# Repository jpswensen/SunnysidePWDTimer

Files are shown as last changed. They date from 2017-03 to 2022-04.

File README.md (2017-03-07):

# SunnysidePWDTimer

This is an early prototype of a simple 4-lane pinewood derby timer created using the popular Internet of Things (IOT) device ESP8266, 
some cheap IR line detectors sensors, and a limit switch for the starting gate.

Parts List
================
* 1) Wemos D1 Mini - $7.49 (https://www.amazon.com/HiLetgo-NodeMcu-Development-ESP8266-Compatiable/dp/B01IXBWH9Y)
* 2) OSOYOO 10PCS IR Infrared Obstacle Avoidance Sensor Module for Arduino Smart Car Robot - $9.99 for a 10 pack (https://www.amazon.com/gp/product/B01I57HIJ0)
* 3) Limit switch for gate sensor (must have normally closed terminals) - $8.89 for a 20 pack (https://www.amazon.com/Gikfun-Micro-Switch-Arduino-EK1713/dp/B015W8S8NA)
* 4) Some 3D printed parts for mounting the sensor to the lanes and the limit switch

Details
================
The project contains both a cross-platform QT5 project for the PC side and Arduino code forht Wemos D1 Mini. They communicate through the
serial port built into the Wemos D1 Mini carrier board for the ESP8266 IOT mainboard. Here is a list of pin configurations:

 * D7 - Start gate limit switch
 * D1 - Lane A
 * D2 - Lane B
 * D5 - Lane C
 * D6 - Lane D

I plan on uploading the Solidworks and STL files for our particular track so that it would be easy for others to modify for their track.
This software is clearly not as fully functional as the Grand Prix Race Manager (TM) software, but it is free and the timer costs about $20-25
if you can get a bit of donated 3D printing from a parent or friend of the pack. I would welcome collaborators to make the software really fully
functional (e.g. support dens/groups/subgroups, printing certificates, etc.) I was actually really surprised when our pack was buying a new track
that was around $1,000 and even a cheap timer was over $219. The timer sold by the track manufacturer was really nice, but cost another $600
beyond the cost of the track.

Let me know if you have any questions and would like to collaborate.

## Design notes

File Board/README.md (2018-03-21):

# SunnysidePWDTimer

This is an initial schematic and board design for an 8-lane pinewood
derby timer.

THIS HAS NOT BEEN TESTED YET. THE CODE AND GUI INCLUDED IN THIS
PROJECT WERE BASED ON A 4-LANE HAND SOLDERED BOARD I MADE. THIS BOARD
IS BASED ON THAT AND SHOULD WORK FOR UP TO 8 LANES, BUT THE ARDUINO
CODE AND GUI CODE HAVE NOT BEEN UPDATED TO WORK WITH THIS DESIGN YET.

Parts List
================
* 1) Wemos D1 Mini - $7.49 (https://www.amazon.com/HiLetgo-NodeMcu-Development-ESP8266-Compatiable/dp/B01IXBWH9Y)
* 2) OSOYOO 10PCS IR Infrared Obstacle Avoidance Sensor Module for Arduino Smart Car Robot - $9.99 for a 10 pack (https://www.amazon.com/gp/product/B01I57HIJ0)
* 3) Limit switch for gate sensor (must have normally closed terminals) - $8.89 for a 20 pack (https://www.amazon.com/Gikfun-Micro-Switch-Arduino-EK1713/dp/B015W8S8NA)
* 4) Some 3D printed parts for mounting the sensor to the lanes and
the limit switch
* 5) See the file SunnysideTimersDigikey.csv for the rest of the
connector, pins, etc from Digikey

In total, I think this time would cost you about $80 to make an 8-lane
timer. If multiple people went together, and it was made in bulk, that
cost could probably be half that much (circuit boards are more
expensive in lower quantity and the cabling is expensive in short lengths). I also chose nice Molex Minifit Jr
connectors which end up being kindof pricy.

Details
================
Here is a description of the files

* SunnysideTimerV1.pro - The project file for Eagle PCB
* SunnysideTimerV1.sch - The schematic file for Eagle PCB
* SunnysideTimerV1.brd - The board file for Eagle PCB

The easiest way to get these made is to go to https://oshpark.com/ and
just upload the .brd file. They do all the processing and the price
comes out at around $30 for 3 boards. Not a bad price for a 14 day turnaround.

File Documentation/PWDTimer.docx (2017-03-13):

Pinewood Derby Timer Documentation

Last updated: 3/11/2017

By: John Swensen (jpswensen@gmail.com)

Overview

Non-technical overview

This is a very basic pinewood derby timer. Among its simple features, it can do the following:

- load/save race information from/to a comma-separated values (CSV) file
- run or re-run each heat of the race
- display and print the results.

It assumed that the track has four lanes and is based on the principle of every car running on every lane and the winner is that average of the times. It is generally understood that even really good tracks have some lanes that are better than others.

The main interface consists of 4 primary regions as seen in the following screen capture. The upper-left region (highlighted in red) contains a complete list of all the heats for the current set of race participants. The lower-left region (highlighted in purple) contains the details of the current heat. The upper-right region (highlighted in orange) contains buttons for configuring the race participants, opening a window with the complete race results, and for configuring the serial port communications with the timer hardware. The lower-right region (highlighted in green) contains buttons for controlling the current heat and some informational text about the current state of the timer hardware and the serial port. Each of these components will be explained later.

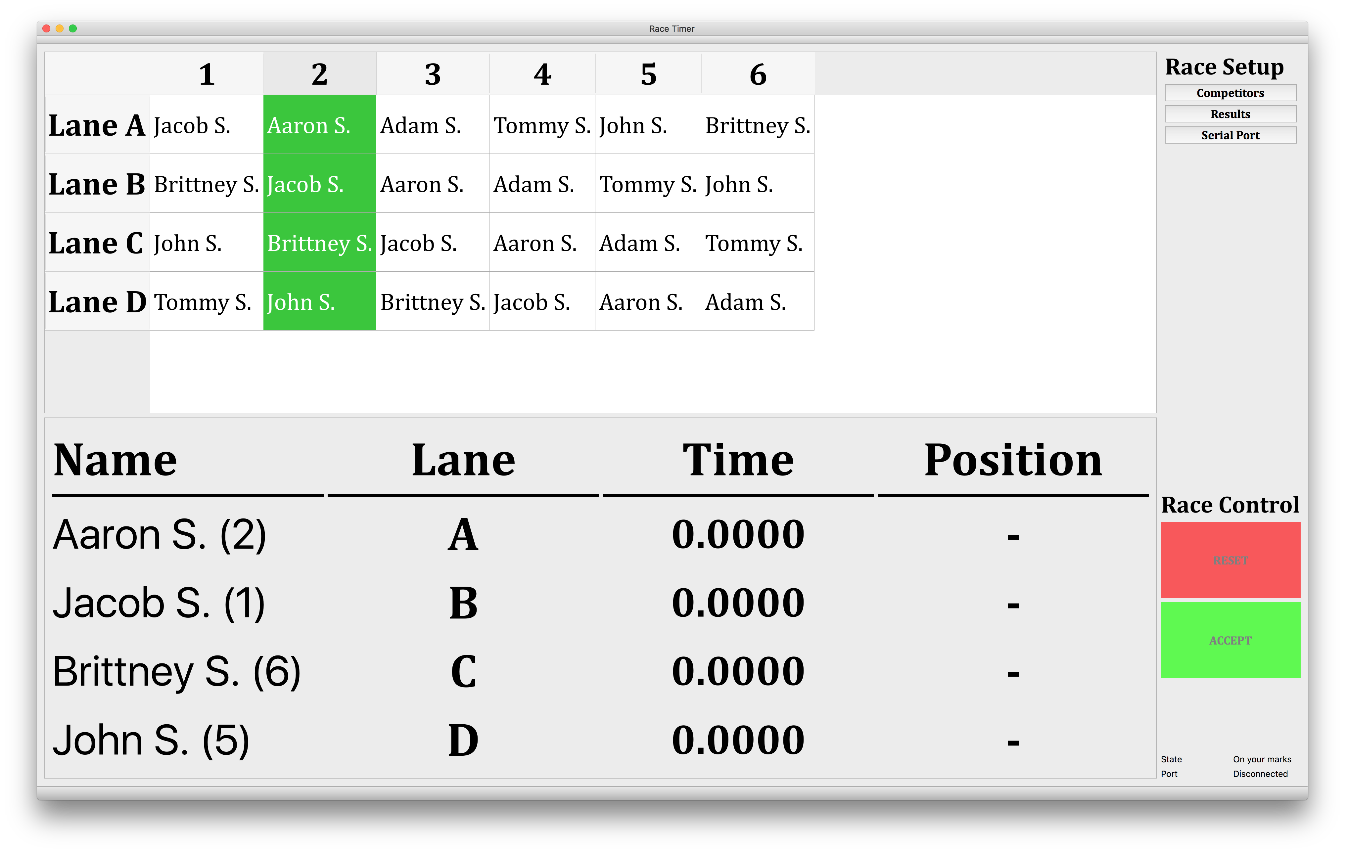
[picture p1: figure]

Technical overview

For the technically inclined, it is an Arduino-compatible ESP8266 microcontroller board (https://www.wemos.cc/product/d1-mini-pro.html ) with one pin interrupt for the start gate switch and four pin interrupts for the IR finish line sensors (https://www.amazon.com/gp/product/B01I57HIJ0). The PC timer software is written using the QT toolkit for cross-platform compatibility. It uses only standard QT toolkit libraries, so it should easily compile for MacOS, Windows, and Linux. The repository for the code can be found at https://github.com/jpswensen/SunnysidePWDTimer.

Quick Start

Import/Save from CSV file

While you can type in the contestants from a Competitors window within the app, many packs have a car check-in the day before. So, the software provides the alternative approach of entering the data into a spreadsheet as saving in CSV form. The import functionality of the timer software requires the follow fields per row: participant name, car name, lane A time, lane B time, lane C time, lane D time.

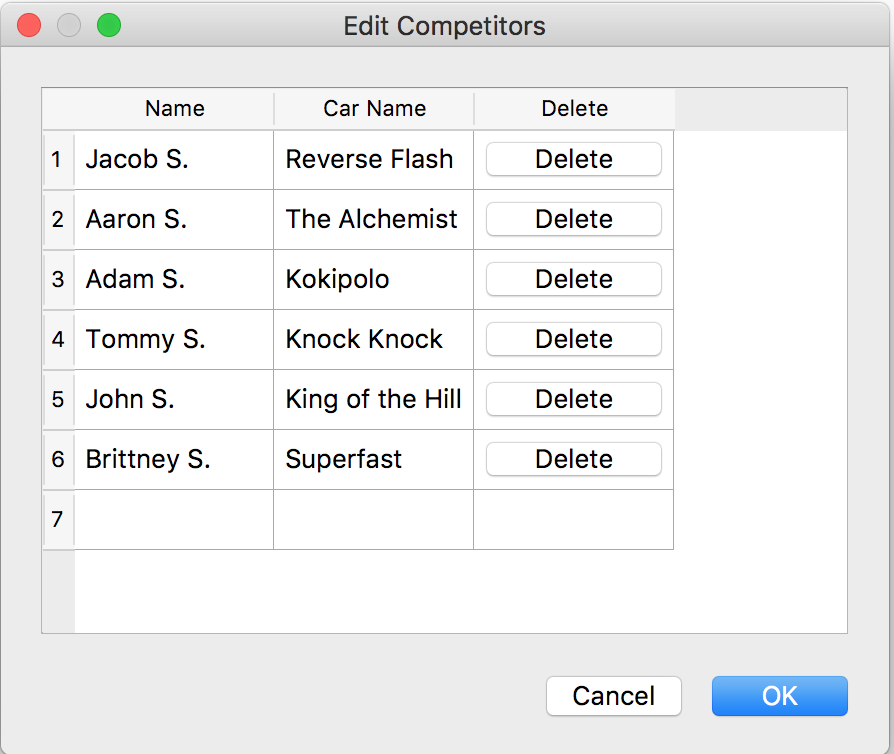
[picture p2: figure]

As the software has still had limited testing, I would recommend saving the race results after every heat is run. In that manner, if there is a crash of the software, then the times from the races that have been completed will not be lost.

Competitors Window

By clicking the Competitors button in the upper-right of the main window, it will open the dialog box shown below that allows the race manager to add and delete participants

WARNING: If the competitors button is used after the race has begun to add/remove a participant, it will clear out all the race time for heats that have already been completed. This is because the addition or removal of a racer will re-arrange how the heats are organized.

Heats Panel of the Main Window

The heats panel is populated by the list of participants, whether from the Competitors window or loaded from a CSV file. With N participants, there will be N heats.

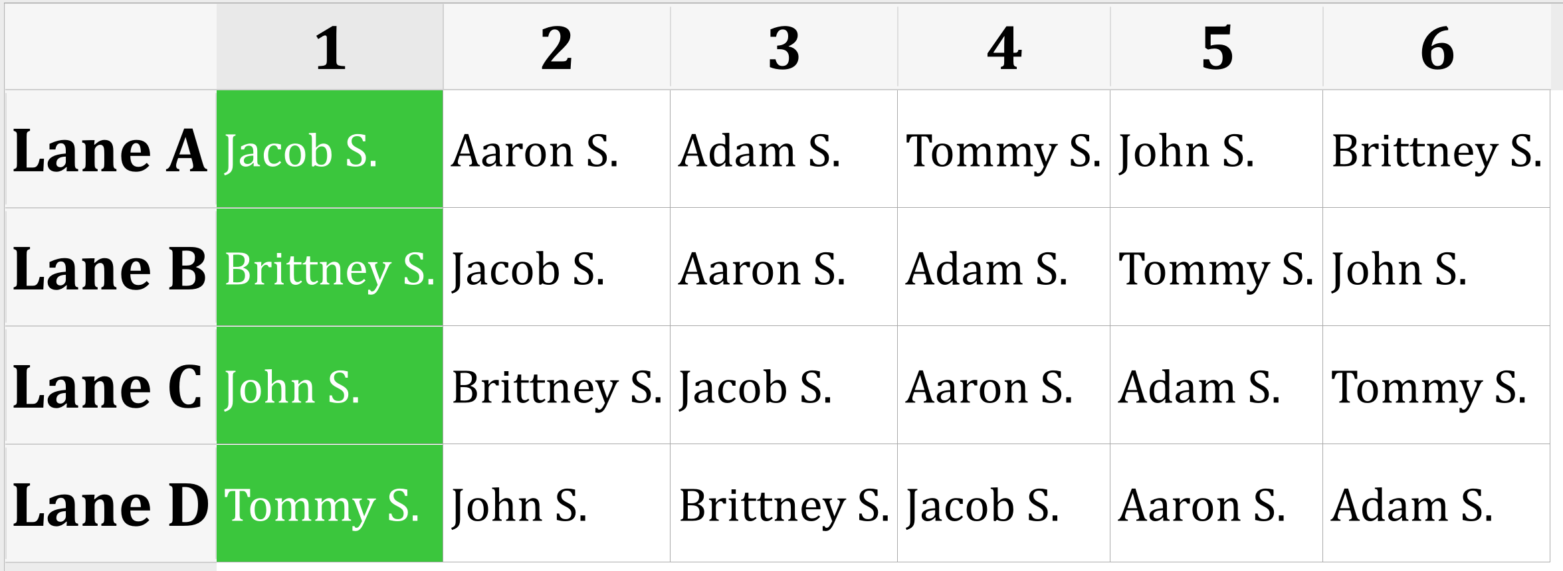
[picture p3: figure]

When the race times for a race heat have been accepted, a red square will appear next to the participant names in any heat that is complete. The race administrator must click on a column to change to a different heat. The current heat is highlighted in green, as shown in the previous figure.

Current Heat Panel of the Main Window

The current heat panel is populated based on which column is selected in the Heats Panel (as described above). This panel not only shows the car number, but also the lane indicator. We recommend having each car place a number on the back of the car during registration that matches the row in the CSV file. Additional put the (A,B,C,D) label on the back of each lane of the track. This will ensure that at the start of each heat it is easy to ensure each car is in the right lane. When the start gate is opened, each participant’s time begins to increase equally until each car crossed the finish line and the time for that lane stops. The participant’s finish position is also displayed. A screenshot of this lower-left panel is shown below. If the heat was successful, the race administrator pressed the “Accept” button to add the times for the current heat and marks the heat as completed in the Heats Panel.

Results Window

The Results window allows the race administrator to show the final results. This window allows the administrator to sort times by clicking on the header for the row. Some racers may be interested to know if they were the fastest on any individual lane, even if they weren’t the overall winners.

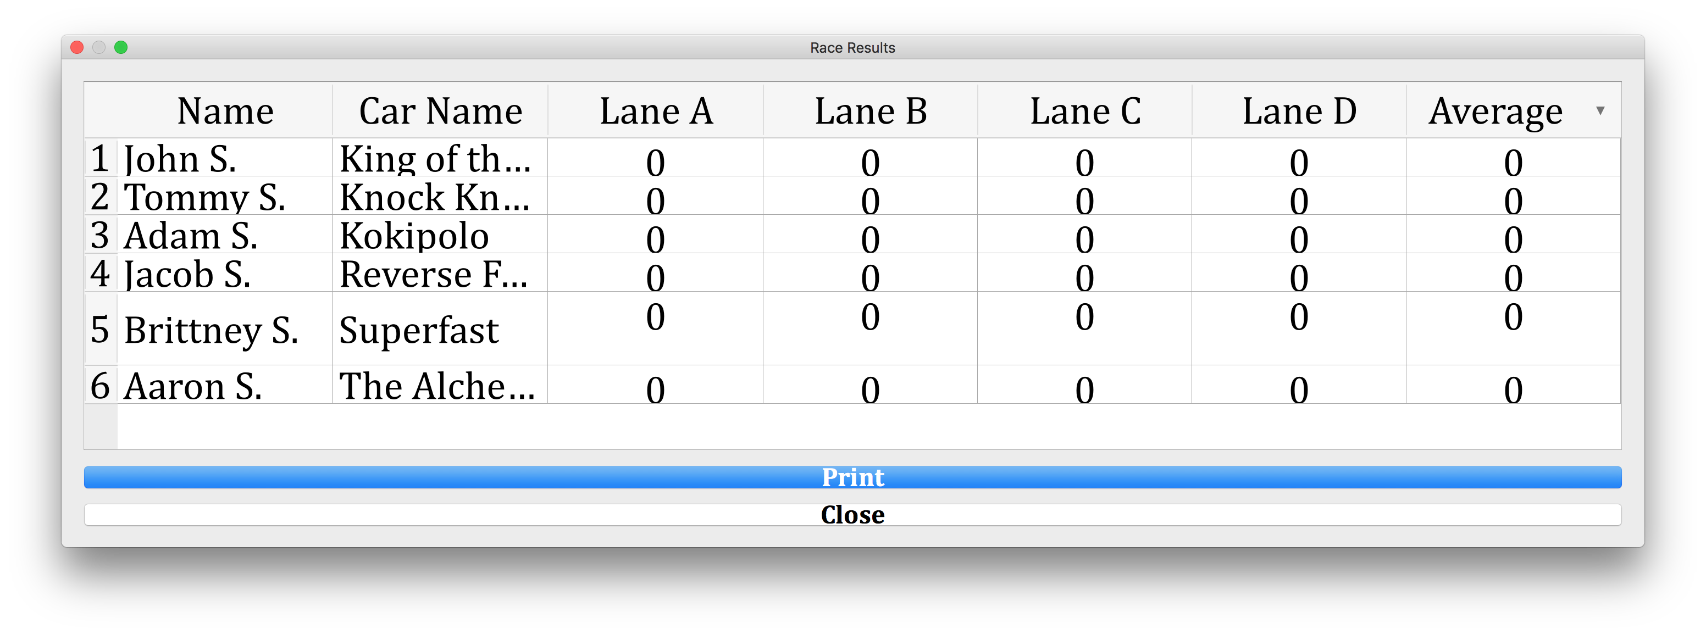
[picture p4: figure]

Serial Port Window

The Serial Port window allows the user to select the serial port used to communicate with the timer. Even though the timer is plugged into your computer using a USB cable, it shows up as a serial port. The easiest way to determine which serial port gets created when the USB cable is plugged in is to first open the Serial Port window before you plug in the timer. Then after you plug in the timer, open the Serial Port window again and see which serial port in the list is new.

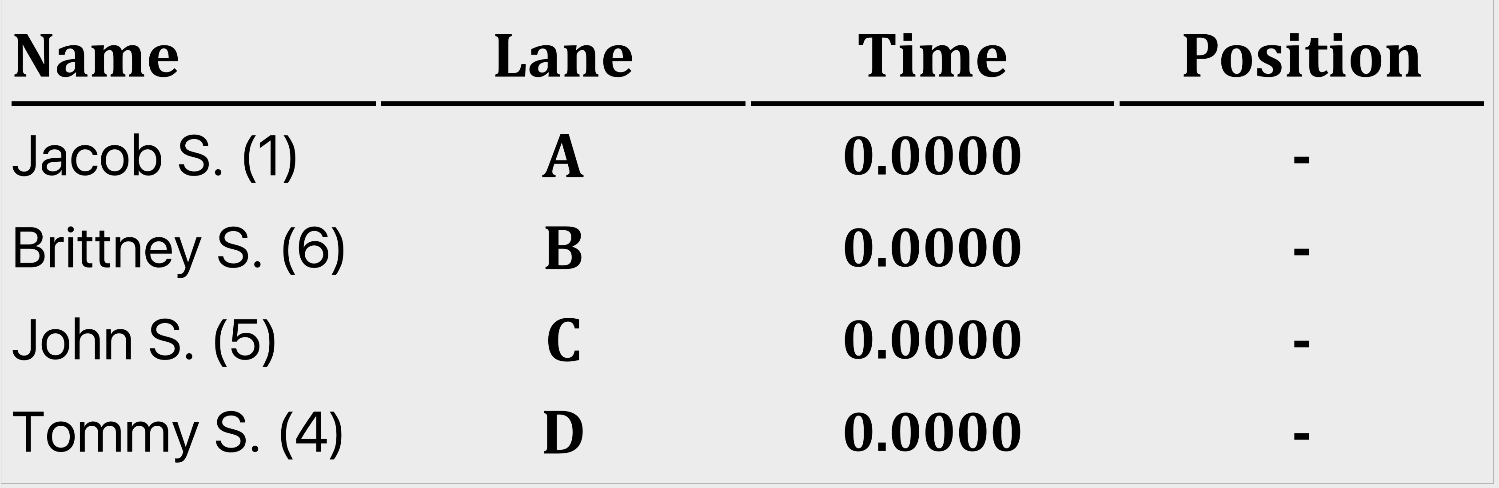
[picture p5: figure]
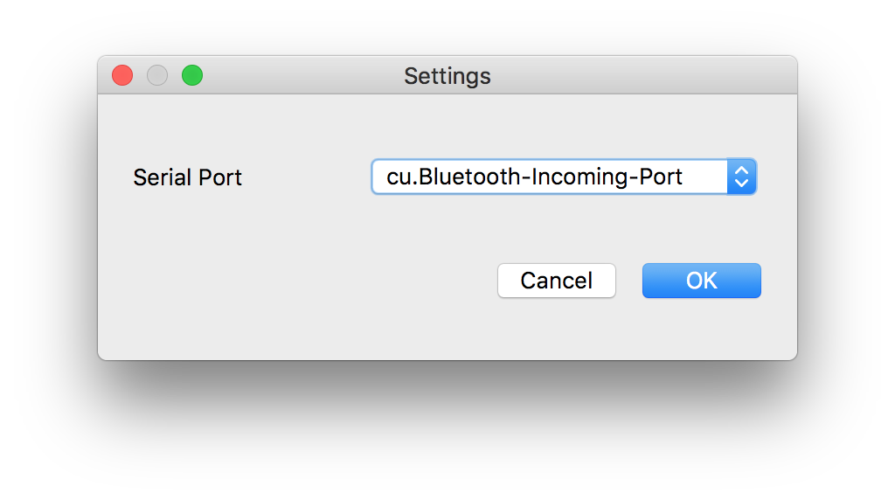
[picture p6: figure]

Race Control Panel

The Race Control panel is used to control the current heat. Due to current communications issues between the timer software and the timer hardware, after the heat has been changed, press the Reset button multiple times until the Time column of the Heat Panel is all zeros (0.0000) and the Position column is empty (‘-‘).

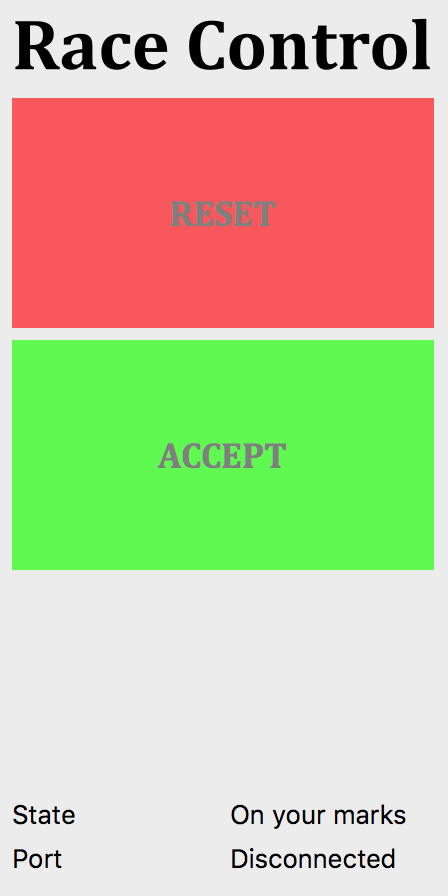
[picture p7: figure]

After the Reset button has been pressed, the State text will change to “On your marks (close gate)”. Once the start gate has been closed, the State text will change to “Get set”. The timer is now just waiting for the gate to be opened.

The Accept button will store the results of the current heat and update the Heats Panel.

Hardware Connections

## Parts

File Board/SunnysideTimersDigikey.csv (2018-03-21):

Index | Quantity | Part Number | Description | Customer Reference | Available Quantity | Backorder Quantity | Unit Price USD | Extended Price USD
1 | 10 | WM3801-ND | CONN HEADER 4POS 4.2MM VERT TIN |  | 10 | 0 | 0.68 | 6.8
2 | 2 | WM3800-ND | CONN HEADER 2POS 4.2MM VERT TIN |  | 2 | 0 | 0.62 | 1.24
3 | 8 | WM3701-ND | CONN RECEPT 4POS DUAL |  | 8 | 0 | 0.31 | 2.48
4 | 2 | WM3700-ND | CONN RECEPT 2POS DUAL |  | 2 | 0 | 0.28 | 0.56
5 | 50 | WM2503-ND | CONN TERM FEMALE 22-28AWG TIN |  | 50 | 0 | 0.1148 | 5.74
6 | 2 | EJ503A-ND | CONN PWR JACK 2.1X5.5MM SOLDER |  | 2 | 0 | 2.02 | 4.04
7 | 2 | 993-1236-ND | AC/DC WALL MOUNT ADAPTER 5V 3W |  | 2 | 0 | 5.26 | 10.52
8 | 1 | CE2104N-25-ND | CABLE 4COND 22AWG NAT SHLD 25' |  | 0 | 1 | 9.15 | 9.15
9 | 1 | C1362-21-50-ND | CABLE SPEAKER 2COND 22AWG 50' |  | 1 | 0 | 10.21 | 21
NONDIGIKEY
Amazon (cheaper from aliexpress) | 2 | WEMOS D1 Mini |  |  | 1 | 0 | $8.99 | 8.99
OshPark | 3 |  |  |  | 3 |  | $10 | 31.1
 |  |  |  |  |  |  |  | 101.62 | TOTAL

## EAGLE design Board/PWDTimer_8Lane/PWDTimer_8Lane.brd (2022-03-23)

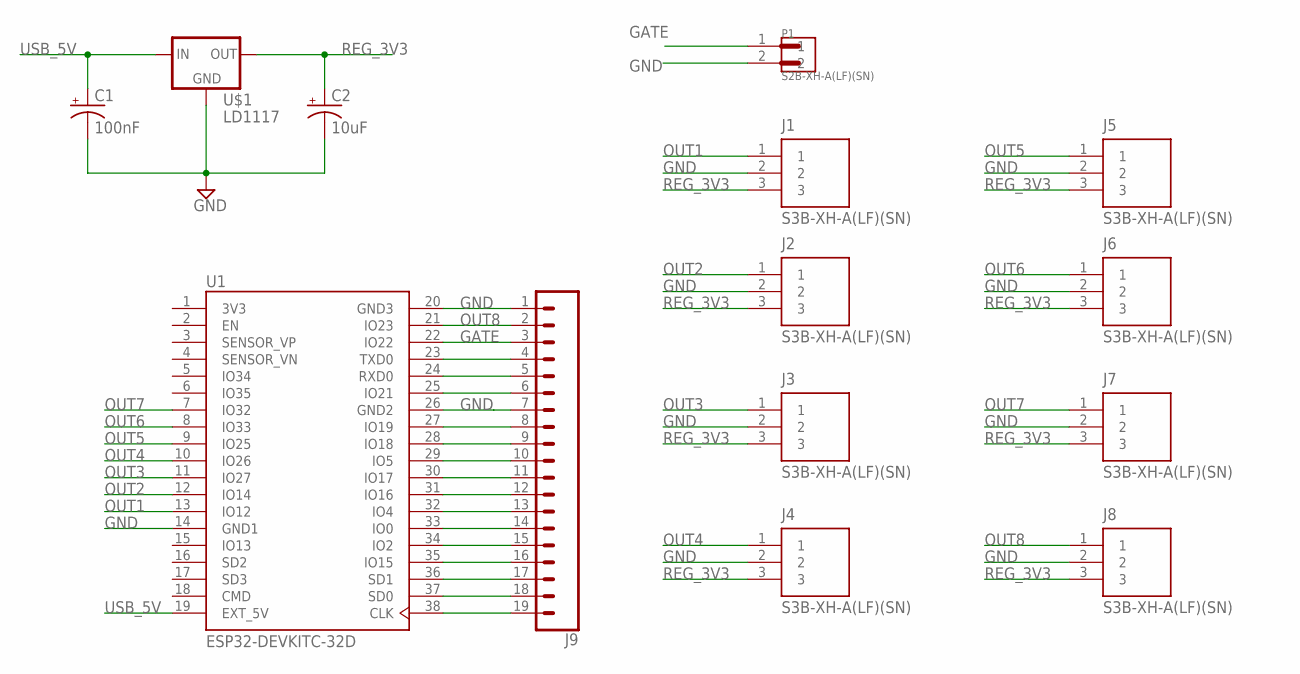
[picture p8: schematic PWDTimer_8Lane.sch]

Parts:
C1: 100nF; CPOL-RADIAL-2.5MM-5MM
C2: 10uF; CPOL-RADIAL-2.5MM-5MM
J1, J2, J3, J4, J5, J6, J7, J8: S3B-XH-A(LF)(SN); JST_S3B-XH-A(LF)(SN)
J9: CONN_191X19_NO_SILK; 1X19_NO_SILK
P1: S2B-XH-A(LF)(SN); JST_S2B-XH-A(LF)(SN)
U1: ESP32-DEVKITC-32D; MODULE_ESP32-DEVKITC-32D
U$1: LD1117; TO220

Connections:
3V3: U1.1 (3V3)
GATE: J9.3, P1.1, U1.22 (IO22)
GND: C1.2 (-), C2.2 (-), J1.2, J2.2, J3.2, J4.2, J5.2, J6.2, J7.2, J8.2, J9.1, J9.7, P1.2, U1.14 (GND1), U1.20 (GND3), U1.26 (GND2), U$1.1 (GND)
unnamed: J9.4, U1.23 (TXD0)
unnamed: J9.5, U1.24 (RXD0)
unnamed: J9.6, U1.25 (IO21)
unnamed: J9.8, U1.27 (IO19)
unnamed: J9.9, U1.28 (IO18)
unnamed: J9.10, U1.29 (IO5)
unnamed: J9.11, U1.30 (IO17)
unnamed: J9.12, U1.31 (IO16)
unnamed: J9.13, U1.32 (IO4)
unnamed: J9.14, U1.33 (IO0)
unnamed: J9.15, U1.34 (IO2)
unnamed: J9.16, U1.35 (IO15)
unnamed: J9.17, U1.36 (SD1)
unnamed: J9.18, U1.37 (SD0)
unnamed: J9.19, U1.38 (CLK)
OUT1: J1.1, U1.13 (IO12)
OUT2: J2.1, U1.12 (IO14)
OUT3: J3.1, U1.11 (IO27)
OUT4: J4.1, U1.10 (IO26)
OUT5: J5.1, U1.9 (IO25)
OUT6: J6.1, U1.8 (IO33)
OUT7: J7.1, U1.7 (IO32)
OUT8: J8.1, J9.2, U1.21 (IO23)
REG_3V3: C2.1 (+), J1.3, J2.3, J3.3, J4.3, J5.3, J6.3, J7.3, J8.3, U$1.2 (OUT)
USB_5V: C1.1 (+), U1.19 (EXT_5V), U$1.3 (IN)

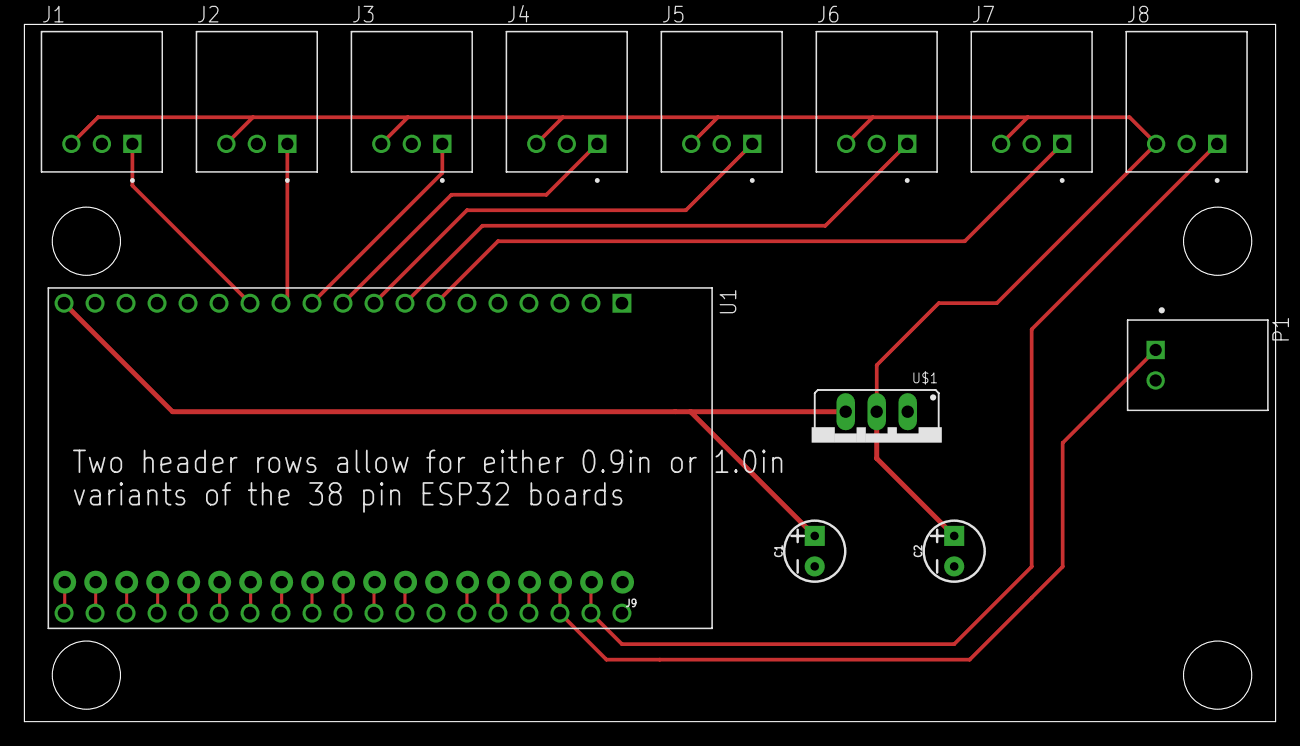
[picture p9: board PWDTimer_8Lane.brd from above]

Board: 2 copper layers, 102.5 x 57.1 mm, 14 parts (0 on the bottom side), 27 nets.

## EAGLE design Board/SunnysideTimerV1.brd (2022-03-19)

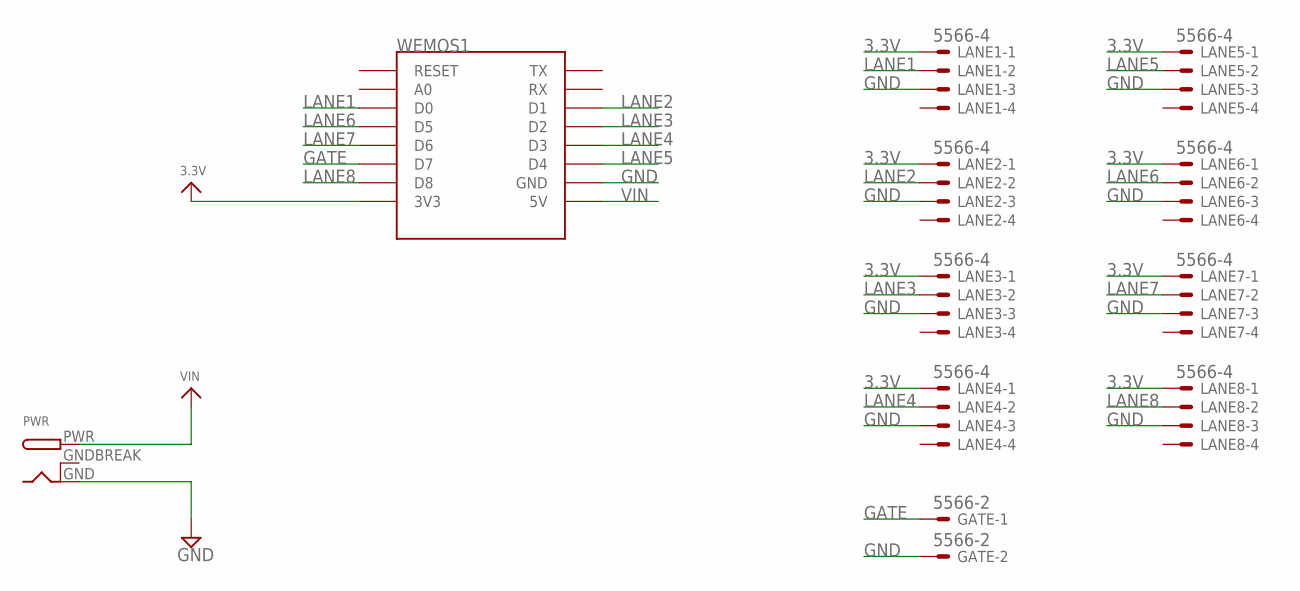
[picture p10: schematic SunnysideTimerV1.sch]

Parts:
GATE: 5566-2
LANE1, LANE2, LANE3, LANE4, LANE5, LANE6, LANE7, LANE8: 5566-4
PWR: DCBARRELPTH; DCJACK_2MM_PTH
WEMOS1: WEMOS-D1-MINI

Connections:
3.3V: LANE1.1, LANE2.1, LANE3.1, LANE4.1, LANE5.1, LANE6.1, LANE7.1, LANE8.1, WEMOS1.3V3
GATE: GATE.1, WEMOS1.D7
GND: GATE.2, LANE1.3, LANE2.3, LANE3.3, LANE4.3, LANE5.3, LANE6.3, LANE7.3, LANE8.3, PWR.GND, WEMOS1.GND
GNDBREAK: PWR.GNDBREAK
LANE1: LANE1.2, WEMOS1.D0
LANE2: LANE2.2, WEMOS1.D1
LANE3: LANE3.2, WEMOS1.D2
LANE4: LANE4.2, WEMOS1.D3
LANE5: LANE5.2, WEMOS1.D4
LANE6: LANE6.2, WEMOS1.D5
LANE7: LANE7.2, WEMOS1.D6
LANE8: LANE8.2, WEMOS1.D8
VIN: PWR.PWR, WEMOS1.5V

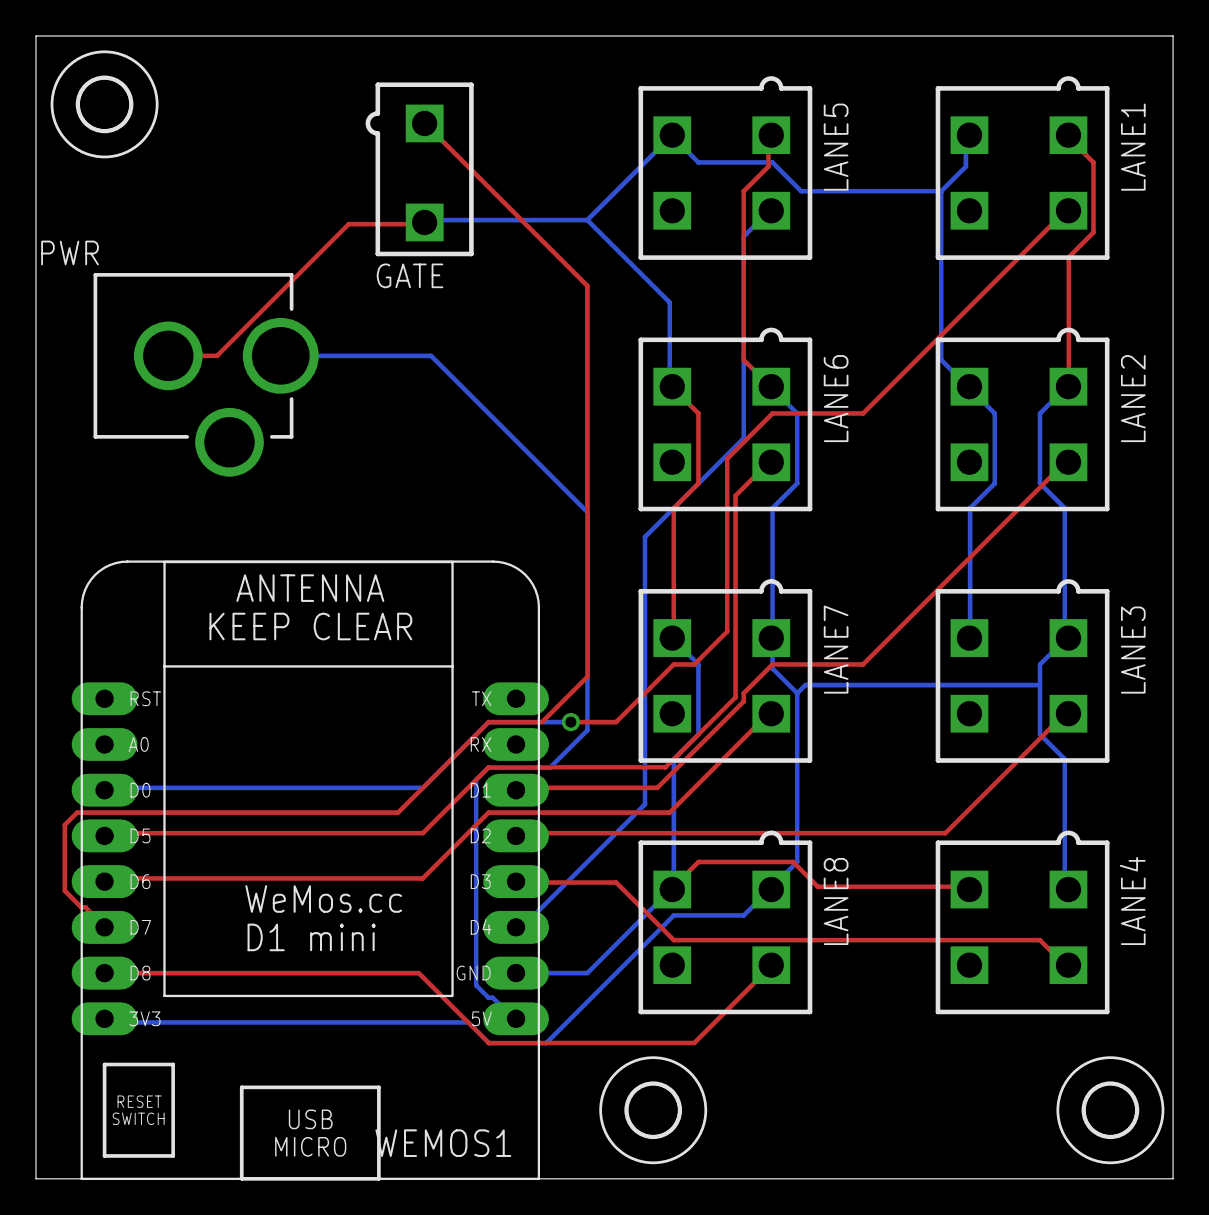
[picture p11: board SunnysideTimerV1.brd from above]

Board: 2 copper layers, 63.2 x 63.5 mm, 14 parts (0 on the bottom side), 12 nets.

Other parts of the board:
U$3, U$4, U$5: 2,8

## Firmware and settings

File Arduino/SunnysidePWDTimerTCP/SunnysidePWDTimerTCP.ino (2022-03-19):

/*
   Copyright (c) 2017, John Swensen
   All rights reserved.

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
   THIS SOFTWARE IS PROVIDED BY THE COPYRIGHT HOLDERS AND CONTRIBUTORS "AS IS" AND
   ANY EXPRESS OR IMPLIED WARRANTIES, INCLUDING, BUT NOT LIMITED TO, THE IMPLIED
   WARRANTIES OF MERCHANTABILITY AND FITNESS FOR A PARTICULAR PURPOSE ARE
   DISCLAIMED. IN NO EVENT SHALL THE COPYRIGHT HOLDER OR CONTRIBUTORS BE LIABLE FOR
   ANY DIRECT, INDIRECT, INCIDENTAL, SPECIAL, EXEMPLARY, OR CONSEQUENTIAL DAMAGES
   (INCLUDING, BUT NOT LIMITED TO, PROCUREMENT OF SUBSTITUTE GOODS OR SERVICES;
   LOSS OF USE, DATA, OR PROFITS; OR BUSINESS INTERRUPTION) HOWEVER CAUSED AND ON
   ANY THEORY OF LIABILITY, WHETHER IN CONTRACT, STRICT LIABILITY, OR TORT
   (INCLUDING NEGLIGENCE OR OTHERWISE) ARISING IN ANY WAY OUT OF THE USE OF THIS
   SOFTWARE, EVEN IF ADVISED OF THE POSSIBILITY OF SUCH DAMAGE.
*/

/* 
  This version of the timer firmware creates a WiFi access point and provides a TCP socket on it.
  This can still be run using the standard serial interface or can be connected to as an access point.
  NOTE: The reason for extending this to a WIFI solution was so that the computer/projector do not
        have to be near the finish line of the race. You will still need to run power to the finish line,
        but you won't need a long USB cable and monitor cable to have a better computer/projector location.
*/

#define USE_US_TIMER 1

#include <ESP8266WiFi.h>
#include <WiFiClient.h>

#include <algorithm>

#define LANE1_PIN D0
#define LANE2_PIN D1
#define LANE3_PIN D2
#define LANE4_PIN D3
#define LANE5_PIN D4
#define LANE6_PIN D5
#define LANE7_PIN D6
#define LANE8_PIN D8

#define STARTGATE_PIN D7



// Enums for maintaining the race and messaging information 
typedef enum RecvMessageEnum {
  UNDEFINED_MSG = 0,
  RESET_MSG
} RecvMessage_t;


typedef enum TimerStateEnum {
  UNDEFINED = 0,
  RESET,
  SET,
  IN_RACE,
  FINISHED
} TimerState_t;


// Variables for determining the state of the race and car times
#define NUM_TIMERS 8
TimerState_t state = RESET;
long startTime = 0;
long endTime[NUM_TIMERS] = {0, 0, 0, 0, 0, 0, 0, 0};


// Variables for configuring the communications
#define SERIAL_BAUD 115200

#define MAX_SRV_CLIENTS 1
#define TCP_PORT        8080

const char *ssid = "PWDTIMER";
const char *password = "PWDTIMER";
WiFiServer server(TCP_PORT);
WiFiClient serverClients[MAX_SRV_CLIENTS];


/**************************************************************************************************************
 * INTERRUPT HANDLING
 **************************************************************************************************************/

// Declare and ISR handler that can deal with any of the lanes
void laneInterrupt(int num)
{
  if (endTime[num] == 0)
  {
    //Serial.println("Lane1 interrupt");
    endTime[num] = micros();

    bool is_finished = true;
    for (int i = 0 ; i < NUM_TIMERS ; i++)
    {
      is_finished &= (endTime[i] != 0);
    }
    state = is_finished ? FINISHED : IN_RACE;    
  }
}

// Create a templated function that uses the ISR number as the template parameter
template<int N>
void laneInterruptISR() {
  laneInterrupt(N);
}

void startGateInterrupt() {
  //Serial.println("Start gate interrupt");
  if (state == SET)
  {
    startTime = micros();
    
    endTime[0] = 0;
    endTime[1] = 0;
    endTime[2] = 0;
    endTime[3] = 0;
    endTime[4] = 0;
    endTime[5] = 0;
    endTime[6] = 0;
    endTime[7] = 0;

    state = IN_RACE;
  }
}
 
void setupInterrupts () {
  // Set up the gate and lane pins as inputs with weak pull-ups
  pinMode(LANE1_PIN, INPUT_PULLUP);
  pinMode(LANE2_PIN, INPUT_PULLUP);
  pinMode(LANE3_PIN, INPUT_PULLUP);
  pinMode(LANE4_PIN, INPUT_PULLUP);
  pinMode(LANE5_PIN, INPUT_PULLUP);
  pinMode(LANE6_PIN, INPUT_PULLUP);
  pinMode(LANE7_PIN, INPUT_PULLUP);
  pinMode(LANE8_PIN, INPUT_PULLUP);
  pinMode(STARTGATE_PIN, INPUT_PULLUP);

  // Attach the interrupts for each of the lanes.
  // NOTE: Here we are using some C++ template magic above to only have to declare the ISR once.
  attachInterrupt(LANE1_PIN, laneInterruptISR<1>, FALLING);
  attachInterrupt(LANE2_PIN, laneInterruptISR<2>, FALLING);
  attachInterrupt(LANE3_PIN, laneInterruptISR<3>, FALLING);
  attachInterrupt(LANE4_PIN, laneInterruptISR<4>, FALLING);
  attachInterrupt(LANE5_PIN, laneInterruptISR<5>, FALLING);
  attachInterrupt(LANE6_PIN, laneInterruptISR<6>, FALLING);
  attachInterrupt(LANE7_PIN, laneInterruptISR<7>, FALLING);
  attachInterrupt(LANE8_PIN, laneInterruptISR<8>, FALLING);

  // Attach the starting gate interrupt
  attachInterrupt(STARTGATE_PIN, startGateInterrupt, FALLING);
}


/**************************************************************************************************************
 * COMMUNICATIONS : TCP (DATA) AND SERIAL (DEBUG)
 **************************************************************************************************************/
void setupCommunications() {
  delay(1000);
  Serial.begin(SERIAL_BAUD);
  Serial.println();

  Serial.print("Setting up soft-AP...");
  boolean result = WiFi.softAP(ssid, password);
  if(result == true)
  {
    IPAddress myIP = WiFi.softAPIP();
    Serial.print("Success!");
    Serial.print("    soft-AP IP address: ");
    Serial.println(myIP);
  }
  else
  {
    Serial.println("Failed to set up soft-AP");
  }

}
    

void setupTCPserver() {  
  server.begin();
  server.setNoDelay(true); 
}

void processTCPserverConnections() {
  uint8_t i;
  if (server.hasClient()){
    for(i = 0; i < MAX_SRV_CLIENTS; i++){
      if (!serverClients[i] || !serverClients[i].connected()){
        if(serverClients[i]) serverClients[i].stop();
        serverClients[i] = server.available();
        continue;
      }
    }
    //no free spot
    WiFiClient serverClient = server.available();
    serverClient.stop();
  }
}

RecvMessage_t readMessage()
{
  // TODO: Check both the serial and the TCP for a message
  
  // Check whether a reset command has been sent via serial
  if (Serial.available() >=5)
  {
    String readString;
    while (Serial.available()) {
      char c = Serial.read();  //gets one byte from serial buffer
      readString += c; //makes the string readString
    }

    
    if (readString.equals("RESET"))
    {
      return RESET_MSG;
    }
  }
  
  return UNDEFINED_MSG;
}

void sendMessage(int currentTime)
{
  // Build the message to be sent
  char msgBuffer[512];
  sprintf(msgBuffer, "$%d,%d,%d,%d,%d,%d,%d,%d,%d,%d,%d*", state, startTime, currentTime,
                     endTime[0], endTime[1], endTime[2], endTime[3],
                     endTime[4], endTime[5], endTime[6], endTime[7]);

  // Send the message over serial
  Serial.println(msgBuffer);

  // Send the message over TCP (if connected)
  if (serverClients[0] && serverClients[0].connected()){
    serverClients[0].println(msgBuffer);
  }
}

/**************************************************************************************************************
 * VARIOUS OTHER FUNCTIONS
 **************************************************************************************************************/
void resetRace() {
  state = RESET;
  startTime = -1;
  for (int i = 0 ; i < NUM_TIMERS ; i++) {
    endTime[i] = 0; 
  }
}


/**************************************************************************************************************
 * SETUP AND LOOP
 **************************************************************************************************************/
void setup() {
  delay(1000);
  setupCommunications();

  setupTCPserver();

  setupInterrupts();
}

void loop() {

  // Process TCP connects and disconnects
  processTCPserverConnections();

  // Read in messages from either serial or TCP
  RecvMessage_t msg = readMessage();
  if (msg == RESET_MSG) {
    resetRace();
  }
  

  long currentTime = -1;
  
  switch (state) {
    case RESET:
      startTime = -1;

      if (digitalRead(STARTGATE_PIN) == HIGH)
      {
        state = SET;
      }
      else
      {
        sendMessage(currentTime);
      }
      
      break;

    case SET:
      sendMessage(currentTime);
      break;

    case IN_RACE:
      currentTime = micros();
      sendMessage(currentTime);
      break;

    case FINISHED:
      currentTime = std::max(std::max(std::max(endTime[0], endTime[1]),endTime[2]),endTime[3]);
      sendMessage(currentTime);
      break;
    
  }

  delay(50);
  
}

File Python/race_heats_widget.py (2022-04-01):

import sys
from PyQt5 import QtWidgets, uic, QtCore
from PyQt5.QtWidgets import *
from PyQt5.QtGui import *
from PyQt5.QtCore import *
import time
import configparser
from pathlib import Path
import os
import typing

from resources import *
from racefiles import *

class RaceHeatsWidget(QWidget):
    num_lanes = 0
    racedata = None
    
    heatSelectionCallback = None

    def __init__(self,parent=None):
        QWidget.__init__(self,parent)
        uic.loadUi(resource_path('race_heats_widget.ui'),self)

        groupsModel = QStandardItemModel()
        groupsModel.setHorizontalHeaderItem(0, QStandardItem("Group"))
        groupsModel.dataChanged.connect(self.on_groups_changed)
        
        self.groupsTreeView.setModel(groupsModel)
        self.groupsTreeView.setSelectionModel(QItemSelectionModel())
        self.groupsTreeView.selectionModel().selectionChanged.connect(self.on_group_selection_changed)

        model = QStandardItemModel(0, 0)
        self.heatsTableView.setModel(model)

    def set_racedata(self, racedata):
        self.racedata = racedata

        model = QStandardItemModel(self.racedata.num_lanes, 0)
        self.heatsTableView.setModel(model)

        self.update_groups_and_heats()

    def set_heat_selection_callback(self, callback):
        self.heatSelectionCallback = callback

    def update_groups_and_heats(self):
        groupsModel = self.groupsTreeView.model()
        groupsModel.removeRows(0, groupsModel.rowCount())

        for group in self.racedata.groups:
            item = QStandardItem(group.name)
            groupsModel.appendRow(item)

        # Select the first item in the treeview (should trigger and update signal for loading the racers)
        index = groupsModel.index(0,0)
        self.groupsTreeView.setCurrentIndex(index)

        self.create_heats_table()

    def create_heats_table(self):
        index = self.groupsTreeView.currentIndex()
        groupRow = index.row()
        
        numRows = 0
        if groupRow != -1:
            numRows = len(self.racedata.groups[groupRow].racers)
        model = QStandardItemModel(self.racedata.num_lanes, numRows)
        for I in range(self.racedata.num_lanes):
            model.setVerticalHeaderItem(I, QStandardItem(f"Lane {I+1}"))

        # for I, part in enumerate(self.participants):
        #     for J in range(self.racedata.num_lanes):
        #         col = (I+J)%len(self.participants)
        #         model.setData(model.index(J,col), part.participantName)

        #         if part.raceTimes[J] != 0:
        #             row, col = self.participantLaneToRowCol(I, J)
        #             # model.setData(model.index(row,col), QVariant(QColor(Qt.red)), Qt.DecorationRole)
        #             model.setData(model.index(row,col), QVariant(self.style().standardIcon(QStyle.SP_DialogApplyButton)), Qt.DecorationRole)
                    
        self.heatsTableView.setModel(model)

        self.heatsTableView.horizontalHeader().setSectionResizeMode(QHeaderView.ResizeMode.Stretch)
        font = QApplication.font() # self.competitorsButton.font()
        font.setPointSize(24)
        self.heatsTableView.horizontalHeader().setFont(font)
        self.heatsTableView.verticalHeader().setFont(font)
        self.heatsTableView.setSelectionBehavior(QAbstractItemView.SelectionBehavior.SelectColumns)
        self.heatsTableView.verticalHeader().setSectionResizeMode(QHeaderView.ResizeMode.ResizeToContents)
        self.heatsTableView.horizontalHeader().setSectionResizeMode(QHeaderView.ResizeMode.ResizeToContents)

        font.setPointSize(16)
        font.setBold(False)
        self.heatsTableView.setFont(font)

        palette = QPalette()
        bg = QColor (50,200,50)
        palette.setColor(QPalette.Highlight,bg)
        palette.setColor(QPalette.HighlightedText, Qt.white)
        self.heatsTableView.setPalette(palette)

        self.populate_heats(groupRow)

        self.heatsTableView.selectionModel().currentColumnChanged.connect(self.on_column_changed)

    def on_groups_changed(self, tleft, bright, roles):
        row = tleft.row()
        col = tleft.column()

        model = self.groupsTreeView.model()
        name = model.data(model.index(row,0))
        self.racedata.groups[row].name = name

    def populate_heats(self, row):

        numRows = 0
        if row == -1:
            return
            
        numRows = len(self.racedata.groups[row].racers)
        newModel = QStandardItemModel(self.racedata.num_lanes,numRows,self)
        for I in range(self.racedata.num_lanes):
            newModel.setVerticalHeaderItem(I, QStandardItem(f"Lane {I+1}"))

        racers = self.racedata.groups[row].racers
        for I,racer in enumerate(racers):                
            for J in range(self.racedata.num_lanes):
                col = (I+J)%len(racers)
                newModel.setData(newModel.index(J,col), racer.name)

                if len(racer.times) > 0 and racer.times[J] != 0:
                    row, col = self.participantLaneToRowCol(I, J)
                    # model.setData(model.index(row,col), QVariant(QColor(Qt.red)), Qt.DecorationRole)
                    newModel.setData(newModel.index(row,col), QVariant(self.style().standardIcon(QStyle.SP_DialogApplyButton)), Qt.DecorationRole)
        
                    
        self.heatsTableView.setModel(newModel)

    def on_group_selection_changed(self, selected, deselected):
        if selected.indexes():
            heatsModel = self.heatsTableView.model()
            heatsModel.removeRows(0, heatsModel.rowCount())

            #row = selected.indexes()[ 0 ].row()
            #self.populate_heats(row)
            self.create_heats_table()

    def on_column_changed(self, index):
        heatNum = index.column()

        index = self.groupsTreeView.currentIndex()
        groupNum = index.row()

        if self.heatSelectionCallback is not None:
            self.heatSelectionCallback(groupNum,heatNum)

        pass

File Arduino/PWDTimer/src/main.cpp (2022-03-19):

#include <Arduino.h>
#include "state.h"
#include "communications.h"
#include "gates.h"
#include <LittleFS.h>   


template<typename T>
T find_max_time(T *arr, size_t n)
{
    return *std::max_element(arr, arr+n);
}

String create_gate_times_message(TimerState_t state, long startTime, long currentTime, int numGates, long* endTimes)
{
  char msgBuffer[512];
  sprintf(msgBuffer, "$%d,%ld,%ld,%d,%ld,%ld,%ld,%ld,%ld,%ld,%ld,%ld*", 
                    state, startTime, currentTime, numGates, 
                    endTimes[0], endTimes[1], endTimes[2], endTimes[3],endTimes[4], endTimes[5], endTimes[6], endTimes[7]);
  return String(msgBuffer);
}

#include "soc/rtc_wdt.h"
void setup() {
  rtc_wdt_protect_off();
  rtc_wdt_disable();
  Serial.begin(115200);
  Serial.println("Waiting for WIFI mode");
  delay(2000);
  
  // put your setup code here, to run once:
  setup_communications();
  setup_gates();    
}


void loop() {
  RecvMessage_t msgType = UNDEFINED_MSG;
  long startTime = -1;
  long endTimes[MAX_LANES];
  
  long currentTime = micros();
  int numGates = get_num_gates();
  read_gates(startTime, endTimes);    

  // Process incoming messages first
  String inMsg = receive_message(msgType);
  if (msgType == RESET_MSG)
  {
    state = RESET;
    reset_gates();
  }
  else if (msgType == SET_LANES_MSG)
  {
    int lanes = get_lanes_from_message(inMsg);
    
    set_num_gates(lanes);
    send_debug_message("Setting the lane count");
  }
  
  // Handle the current state of the system
  switch (state) {
    case RESET:
    {
      startTime = -1;      

      if (is_starting_gate_set())
      {
        state = SET;
      }      
      break;
    }
    case SET:
    {
      break;
    }
    case IN_RACE:
    {
      bool is_finished = true;
      for (int i = 0 ; i < numGates ; i++)
      {
        is_finished &= (endTimes[i] != 0);
      }
      state = is_finished ? FINISHED : IN_RACE;                      
      break;
    }
    case FINISHED:
    {
      currentTime = find_max_time(endTimes,numGates);
      break;
    }
    default:
    {
      send_debug_message("UNKNOWN STATE");
      break;
    }
  }

  // Send out a message regardless of which state we are in that contains the 
  String outMessage = create_gate_times_message(state, startTime, currentTime, numGates, endTimes);
  send_message(outMessage);

  delay(50);

  
}

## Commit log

2017-03-04 Switched to using the serial port (then we can just plug into whatever computer we are using). It also seems to transmit faster. I also think I have all of the logic working for resetting the timer, 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
2017-03-04 Added the Arduino/ESP8266 code to the repository. Now that I switched to serial, this should work with basically any Arduino-compatible microcontroller that has at least 5 pins with interrupt-on-chan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
2017-03-04 I almost have the basics of the heats panel completed. There is still no interaction between the heats panel and the single heat panel, but the basics are there.
2017-03-05 Finished up the heats panel, load & save from CSV, and participant editor. I need to clean the code up quite a bit, but it is looking OK. I did notice it looks kindof bad on my Mac when not connected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
2017-03-05 Starting to comment a bit, in the case anyone wants to help out.
2017-03-06 Added the printable results view. Various other small fixes. Other than a dialog that allows the selection of the serial port and a little better interaction between the microcontroller and the deskt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
2017-03-13 Various bug fixed for crashes when the serial port isn't open. Added some beginning documentation.
    [SunnysidePWDTimer.ino]
2017-03-18 Adjusted font sizes. Error proofed the reset button. Auto-resize the results rows.
2018-03-21 Added the initial circuit board design and description to the repository
    [SunnysideTimerV1.brd, SunnysideTimerV1.sch, SunnysideTimersDigikey.csv]
2018-03-22 Added an updated firmware version that can handle up to 8 lanes and can communicate over a TCP socket (it sets itself up as a WIFI access point)
2022-03-19 Lots of updates, but haven't had the time to organize it and remove the old stuff. This is a halfway step to a much, much better timer. The design has been updated to use an ESP32 instae of the ESP82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
    [PWDTimer_8Lane.brd, PWDTimer_8Lane.sch, SunnysideTimerV1.brd]
2022-03-19 Fixed a bug on serial receive if any garbage characters come in (e.g. from board resetting)
    [pwdtimer_communications.py]
2022-03-23 Lots of updates to changing how data is stored as a json file, as well as starting the conversion to having groups and racers in the groups instead of just one monolothic racer group.
    [PWDTimer_8Lane.brd, PWDTimer_8Lane.sch]
2022-03-24 Almost completed the switchover from everything being in the main UI file, to having a separate ui file and python file for each tab panel. This should also make it easier to make 'plugins' for futur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
2022-04-01 This seems fairly close to MVP status. I have tested the serial communications thoroughly. Fixed a bug where serial wouldn't start working until Wifi succeeded. Connect and disconnect seems to work. 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
    [commdialog.py, communications.cpp, current_race_widget.py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]

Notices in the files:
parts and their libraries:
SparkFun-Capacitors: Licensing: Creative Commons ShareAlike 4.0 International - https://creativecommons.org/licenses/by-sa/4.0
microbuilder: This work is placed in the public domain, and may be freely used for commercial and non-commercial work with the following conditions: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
